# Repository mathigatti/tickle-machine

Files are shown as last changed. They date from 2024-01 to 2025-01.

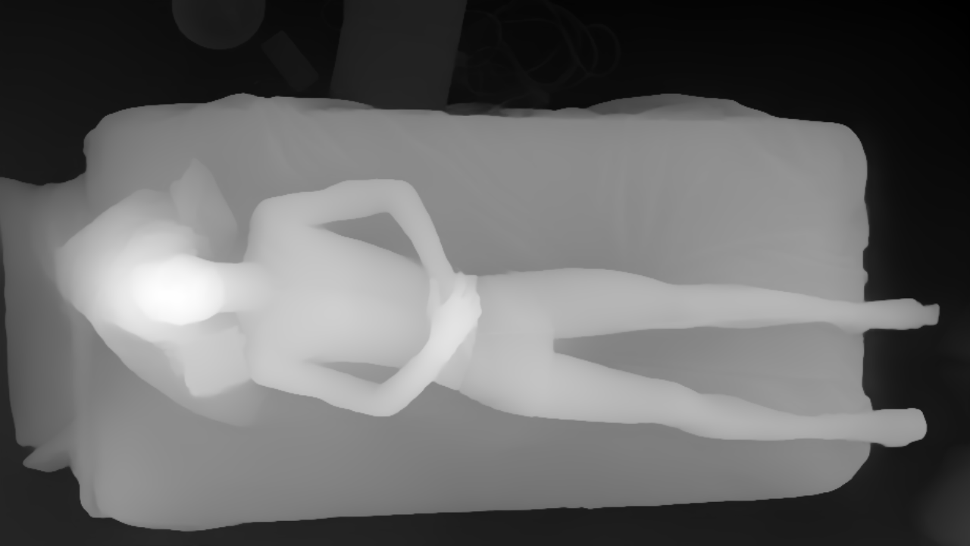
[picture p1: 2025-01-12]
src/move/depth.png

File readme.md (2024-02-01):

notas

- pi x diamtetro x vueltas = cantida de cable recorrido
- microsteps se habilitan mandando m0, m1 y m2 a 5V. (2,4,8, ... 32) del DRV. Una vuelta sin microsteps es 200 sin microsteps, con los microsteps gana mucho torque
- seteo potencimetro del dvr. Arrancar girando todo en sentido horario y probando girarlo de a poco hasta que ande, chequeando tambien que no caliente mucho

## cuestiones de montaje
para la sujecion de motores recomiendo utilizar [esta pieza 3d](https://www.thingiverse.com/thing:3539999) o similes
 * medidas de tornillos M3 x 6 mm

A su vez en el proyecto se encuentran poleas desarrolladas para el caso.
* pensadas para utilizar un tornillo y tuerca  de 5/32 x 3/4 (20mm)
  se realizo una prueba en [poleas para cadenas de cortinas](https://www.thingiverse.com/thing:3147) blackout pero fue descartado por el error acumulado; dejando el diseño del mismo para futuras investigaciones 

# para la proxima

- ver de usar el ramp
- incorporar segundo motor y empezar a investigar como manejarlos

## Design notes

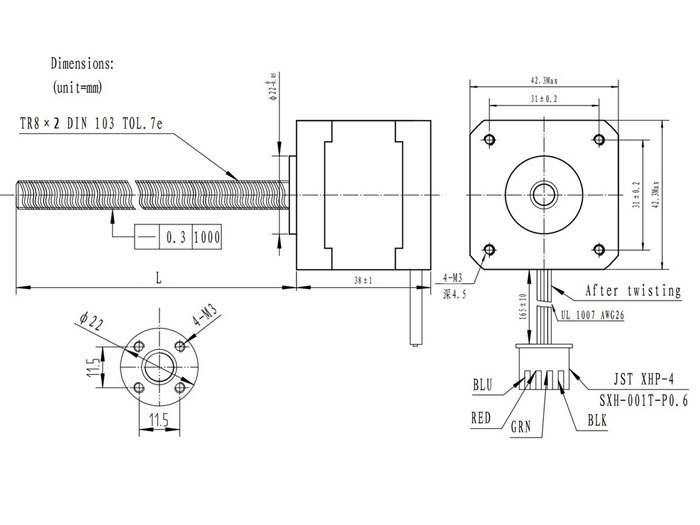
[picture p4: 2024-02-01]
ref tecnicas/mmpp038b.jpg

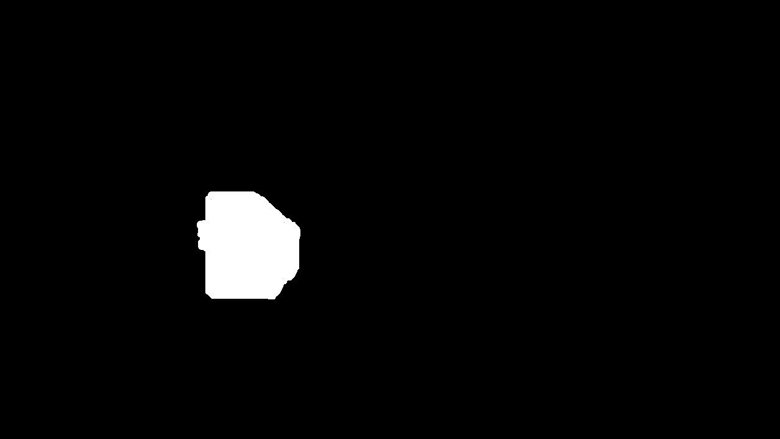
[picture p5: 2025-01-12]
src/move_simplified/mask.jpg

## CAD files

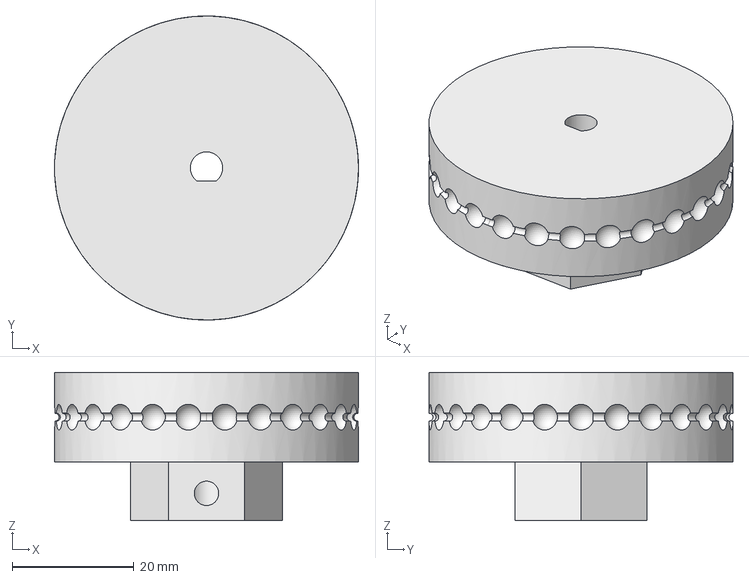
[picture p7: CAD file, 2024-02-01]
modelos 3d/desings/freecad/agarre parametrico y cortina.FCStd
49.9 x 49.9 x 24.4 mm

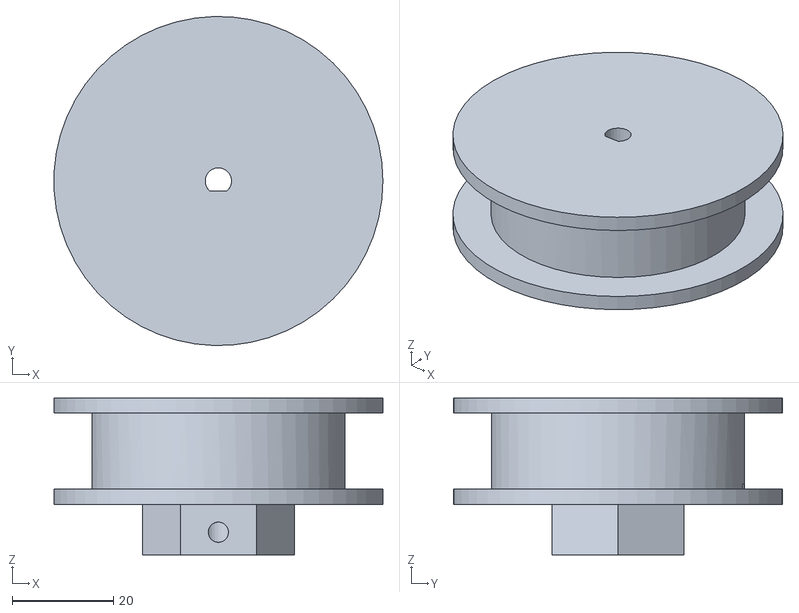
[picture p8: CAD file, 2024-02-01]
modelos 3d/stls/carretel_v4-base.stl
64.9 x 65.0 x 31.0

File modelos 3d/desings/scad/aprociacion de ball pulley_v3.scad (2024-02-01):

tolerancia=0.015;
offset_whell=0;
detalle=20;
ball_diameter = tolerancia+ 4.2;
ball_count = 96; // for regular pully;wd
link_largo =   tolerancia+  1.8;
// ball_spacing = 5.1; // The distance from the centre of one ball to the next
ball_spacing = ball_diameter+link_largo; // The distance from the centre of one ball to the next
//link_diameter = 0.9;
link_diameter =  tolerancia+  1.28;

PI = 3.1415927;
wheel_diameter =  tolerancia+  ball_count*ball_spacing / PI;
wheel_height =   ball_diameter*3.5;

pulley_height = wheel_height ;

module pulley () {
 difference(){
	difference()
	{
		cylinder (pulley_height, r = wheel_diameter/2+offset_whell, center=true, $fn = ball_count);

		for (i = [1:ball_count])
		{	
			rotate ([0, 0, (360/ball_count) * i])		
			translate ([wheel_diameter/2,0,0])
			sphere (r = ball_diameter/2,$fn=detalle);
     
		}

	}
  	
		rotate ([0, 0, -90]) // Rotate -90 to match face direction of cylinder
		rotate_extrude (convexity = 5, $fn = ball_count)
		translate ([wheel_diameter/2, 0, 0])
		circle (r = link_diameter/2, center = true);
 }
}

//translate ([0, 0, pulley_height/2])
pulley(); 

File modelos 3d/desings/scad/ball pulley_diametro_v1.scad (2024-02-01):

PI = 3.1415927;

tolerancia=0.015;
detalle=20;
diametro_ideal=50;

ball_diameter = tolerancia+ 4.2;
//cantidad = 96; // for regular pully;wd
link_largo =   tolerancia+  1.8;
espaciado = ball_diameter+link_largo; 

cantidad= round(diametro_ideal/espaciado*PI);
//echo(cantidad);

//link_diameter = 0.9;
link_diameter =  tolerancia+  1.28;

diametro =  cantidad*espaciado / PI;
altura =   ball_diameter*3.5;

altura_agarre = altura ;

module pulley () {
 difference(){
	difference()
	{
		cylinder (altura_agarre, r = diametro/2, center=true, $fn = cantidad);

		for (i = [1:cantidad])
		{	
			rotate ([0, 0, (360/cantidad) * i])		
			translate ([diametro/2,0,0])
			sphere (r = ball_diameter/2,$fn=detalle);
     
		}

	}
  	
		rotate ([0, 0, -90]) // Rotate -90 to match face direction of cylinder
		rotate_extrude (convexity = 5, $fn = cantidad)
		translate ([diametro/2, 0, 0])
		circle (r = link_diameter/2, center = true);
 }
}

//translate ([0, 0, altura_polea/2])
pulley(); 

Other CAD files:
modelos 3d/desings/freecad/carretel_v4.FCStd
modelos 3d/stls/agarre y polea cortina v1.stl

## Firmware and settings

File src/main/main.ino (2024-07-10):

#include <AccelStepper.h>

#define X_STEP_PIN A0
#define X_DIR_PIN A1
#define X_ENABLE_PIN 38

#define Y_STEP_PIN 46
#define Y_DIR_PIN 48
#define Y_ENABLE_PIN A8

#define Z_STEP_PIN A6
#define Z_DIR_PIN A7
#define Z_ENABLE_PIN A2

#define X_MIN 3
#define Y_MIN 18
#define Z_MIN 14

// Global variables
double x_total_cm = 20;
double z_total_cm = 19;

double diametro_cm = 5;
double perimetro = PI * diametro_cm;
int steps_por_vuelta = 6400;
double cm_a_steps = steps_por_vuelta / perimetro;
int steps_m1, steps_m2, steps_m3;

// Constantes

struct Vector {
  double x;
  double y;
  double z;
};

// Valores de inicio
double largo_motor_1 = 15;
double largo_motor_2 = x_total_cm-largo_motor_1;
double largo_motor_3 = 42;

Vector posiciones[] = {
  {100.0, 100.0, 100.0}
};

int lenVector = sizeof(posiciones) / sizeof(posiciones[0]);
int idx = 0;

void printear(String s, double val) {
  Serial.print(s + " : ");
  Serial.println(val);
}

void printear(String s, int val) {
  Serial.print(s + " : ");
  Serial.println(val);
}
void printear(String s, float val) {
  Serial.print(s + " : ");
  Serial.println(val);
}

void printear(String s, char val) {
  Serial.print(s + " : ");
  Serial.println(val);
}

void printear(String s, long val) {
  Serial.print(s + " : ");
  Serial.println(val);
}


void printear(String s) {
  Serial.println(s);
}

void calibrar_motores(AccelStepper motorX, AccelStepper motorY, AccelStepper motorZ, int *steps_motor_1, int *steps_motor_2, int *steps_motor_3) {
  /* ESTE CODIGO ASUME QUE EL MOTOR X TIENE HILO DE SOBRE SIEMPRE */
  int callibrate_steps = int(10 * cm_a_steps);
  // 1.
  // Mover motorX hasta que apriete el final de carrera
  bool X_SET = false;

  while (!X_SET) {
    motorX.move(-1*callibrate_steps);

    while (!X_SET && abs(motorX.distanceToGo()) > 0) {
      motorX.run();

      if (digitalRead(X_MIN) == LOW){
        X_SET = true;
      }

    }

  }

  Serial.println(digitalRead(X_MIN));

  bool Y_SET = false;
  bool Z_SET = false;
  *steps_motor_1 = 0;
  *steps_motor_2 = 0;
  // 2.
  // Mover motores hasta que se apriete el final de carrera del motorY
  while (!Y_SET) {
    motorY.move(-1*callibrate_steps);
    motorX.move(callibrate_steps);
    while (!Y_SET && abs(motorY.distanceToGo()) > 0) {
      motorY.run();
      motorX.run();
      *steps_motor_1+=1;
      if (digitalRead(Y_MIN) == LOW){
        Y_SET = true;
      }

    }
  }
  Serial.println(digitalRead(Y_MIN));

  *steps_motor_3 = 0;

  // FALTA HACER CALCULO DE QUE X SE VA A MOVER LA DISTANCIA DE X A Z MENOS LO QUE TIENE AHORA DE SOGA
  //motorX.move(COMPLETAR);

  while (!Z_SET) {
    motorY.move(callibrate_steps);
    motorZ.move(-1*callibrate_steps);
    while (!Z_SET && abs(motorZ.distanceToGo()) > 0) {
      //motorX.run();
      motorY.run();
      motorZ.run();
      *steps_motor_1+=1;
      *steps_motor_2+=1;
      if (digitalRead(Z_MIN) == LOW){
        Z_SET = true;
      }

    }
  }
  Serial.println(digitalRead(Y_MIN));

}



void update_steps(double x, double y, double z, int *steps_motor_1, int *steps_motor_2, int *steps_motor_3) {
  double largo_motor_1_viejo = largo_motor_1;
  double largo_motor_2_viejo = largo_motor_2;
  double largo_motor_3_viejo = largo_motor_3;

  largo_motor_1 = sqrt(pow(x, 2) + pow(y, 2) + pow(z, 2));
  largo_motor_2 = sqrt(pow(x_total_cm - x, 2) + pow(y, 2) + pow(z, 2));
  largo_motor_3 = sqrt(pow(x_total_cm/2 - x, 2) + pow(y, 2) + pow(z_total_cm - z, 2));

  double diferencia_motor_1 = largo_motor_1 - largo_motor_1_viejo;
  double diferencia_motor_2 = largo_motor_2 - largo_motor_2_viejo;
  double diferencia_motor_3 = largo_motor_3 - largo_motor_3_viejo;

  *steps_motor_1 = int(cm_a_steps * diferencia_motor_1);
  *steps_motor_2 = int(cm_a_steps * diferencia_motor_2);
  *steps_motor_3 = int(cm_a_steps * diferencia_motor_3);
}


int x_i;
int y_i;
int z_i;


int numberOfSteps = 400;
byte ledPin = 13;
int pulseWidthMicros = 20;    // microseconds
int millisbetweenSteps = 20;  // milliseconds - or try 1000 for slower steps

int vueltas = 4;
int steps = 200;
int microsteps = 32;

AccelStepper motorY(1, Y_STEP_PIN, Y_DIR_PIN);
AccelStepper motorX(1, X_STEP_PIN, X_DIR_PIN);
AccelStepper motorZ(1, Z_STEP_PIN, Z_DIR_PIN);

void setup() {

  Serial.begin(9600);
  Serial.println("Starting StepperTest");
  digitalWrite(ledPin, LOW);

  pinMode(X_MIN, INPUT);
  pinMode(Y_MIN, INPUT);
  pinMode(Z_MIN, INPUT);

  pinMode(Y_STEP_PIN, OUTPUT);
  pinMode(Y_DIR_PIN, OUTPUT);
  pinMode(Y_ENABLE_PIN, OUTPUT);

  pinMode(X_STEP_PIN, OUTPUT);
  pinMode(X_DIR_PIN, OUTPUT);
  pinMode(X_ENABLE_PIN, OUTPUT);

  pinMode(Z_STEP_PIN, OUTPUT);
  pinMode(Z_DIR_PIN, OUTPUT);
  pinMode(Z_ENABLE_PIN, OUTPUT);

  pinMode(ledPin, OUTPUT);

  int speed = int(steps * microsteps);
  motorY.setMaxSpeed(speed * 2);
  motorY.setSpeed(speed);
  motorY.setAcceleration(speed * 4);

  motorX.setMaxSpeed(speed * 2);
  motorX.setSpeed(speed);
  motorX.setAcceleration(speed * 4);

  motorZ.setMaxSpeed(speed * 2);
  motorZ.setSpeed(speed);
  motorZ.setAcceleration(speed * 4);

  calibrar_motores(motorX, motorY,motorZ, &steps_m1, &steps_m2, &steps_m3);
}

void loop() {
  /*
  int max_position = steps * microsteps * vueltas;
  motorY.run();
  motorX.run();
  motorZ.run();

  if (motorY.distanceToGo() == 0 && motorX.distanceToGo() == 0 && motorZ.distanceToGo() == 0) {
    printear("-----------------------");
    printear("currentPosition", motorX.currentPosition());

    printear("cambio objetivo");

    idx++;
    if (idx == lenVector) {
      idx = 0;
    }
    x_i = posiciones[idx].x;
    y_i = posiciones[idx].y;
    z_i = posiciones[idx].z;
    printear("posX destino", x_i);
    update_steps(x_i, y_i, z_i, &steps_m1, &steps_m2, &steps_m3);

    motorY.move(-steps_m1);
    motorX.move(steps_m2);
    motorZ.move(steps_m3);
    printear("steps_m1", steps_m1);
    printear("steps_m2", steps_m2);
    printear("steps_m2", steps_m3);

    printear("-----------------------");

    delay(2000);

  }
  */
}

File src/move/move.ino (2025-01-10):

#include <AccelStepper.h>

#define X_STEP_PIN A0
#define X_DIR_PIN A1
#define X_ENABLE_PIN 38

#define Y_STEP_PIN 46
#define Y_DIR_PIN 48
#define Y_ENABLE_PIN A8

#define Z_STEP_PIN A6
#define Z_DIR_PIN A7
#define Z_ENABLE_PIN A2

#define X_MIN 3
#define Y_MIN 18
#define Z_MIN 14

double diametro_cm = 5;
double perimetro = PI * diametro_cm;
int steps_por_vuelta = 6400;
double cm_a_steps = steps_por_vuelta / perimetro;

AccelStepper motorX(1, X_STEP_PIN, X_DIR_PIN);
AccelStepper motorY(1, Y_STEP_PIN, Y_DIR_PIN);
AccelStepper motorZ(1, Z_STEP_PIN, Z_DIR_PIN);

int numberOfSteps = 400;
byte ledPin = 13;
int pulseWidthMicros = 20;    // microseconds
int millisbetweenSteps = 20;  // milliseconds - or try 1000 for slower steps

int vueltas = 4;
int steps = 200;
int microsteps = 32;

// Struct for 3D coordinates
struct Coordinate3D {
  double x;
  double y;
  double z;
};

double movement_length = 10.;

void handle_serial_command(char command) {
  switch (command) {
    case 'N': // Moverse mas
      movement_length += 1;
      if (movement_length > 100)
        movement_length = 100;
      break;
    case 'M': // Moverse menos
      movement_length -= 1;
      if (movement_length < 1)
        movement_length = 1;
      break;
    case 'Y': // Motor X Up
      motorX.move(cm_a_steps * -movement_length);
      break;
    case 'H': // Motor X Down
      motorX.move(cm_a_steps * movement_length);
      break;
    case 'U': // Motor Y Up
      motorY.move(cm_a_steps * -movement_length);
      break;
    case 'J': // Motor Y Down
      motorY.move(cm_a_steps * movement_length);
      break;
    case 'I': // Motor Z Up
      motorZ.move(cm_a_steps * -movement_length);
      break;
    case 'K': // Motor Z Down
      motorZ.move(cm_a_steps * movement_length);
      break;
    default:
      break;
  }
}

void setup() {
  Serial.begin(9600);
  Serial.println("Starting StepperTest");
  digitalWrite(ledPin, LOW);

  pinMode(X_MIN, INPUT);
  pinMode(Y_MIN, INPUT);
  pinMode(Z_MIN, INPUT);

  pinMode(Y_STEP_PIN, OUTPUT);
  pinMode(Y_DIR_PIN, OUTPUT);
  pinMode(Y_ENABLE_PIN, OUTPUT);

  pinMode(X_STEP_PIN, OUTPUT);
  pinMode(X_DIR_PIN, OUTPUT);
  pinMode(X_ENABLE_PIN, OUTPUT);

  pinMode(Z_STEP_PIN, OUTPUT);
  pinMode(Z_DIR_PIN, OUTPUT);
  pinMode(Z_ENABLE_PIN, OUTPUT);

  pinMode(ledPin, OUTPUT);

  int speed = int(steps * microsteps * 20);
  //speed = 30000;
  
  motorY.setMaxSpeed(speed * 2);
  motorY.setSpeed(speed);
  motorY.setAcceleration(speed * 4);

  motorX.setMaxSpeed(speed * 2);
  motorX.setSpeed(speed);
  motorX.setAcceleration(speed * 4);

  motorZ.setMaxSpeed(speed * 2);
  motorZ.setSpeed(speed);
  motorZ.setAcceleration(speed * 4);


}

Coordinate3D parse_coordinates(String message) {
  // Assuming message is in the format "x,y,z"
  Coordinate3D coord;
  int firstCommaIndex = message.indexOf(',');
  int secondCommaIndex = message.indexOf(',', firstCommaIndex + 1);

  if (firstCommaIndex == -1 || secondCommaIndex == -1) {
    Serial.println("Invalid coordinate format");
    return coord;
  }

  String xString = message.substring(0, firstCommaIndex);
  String yString = message.substring(firstCommaIndex + 1, secondCommaIndex);
  String zString = message.substring(secondCommaIndex + 1);

  coord.x = xString.toFloat();
  coord.y = yString.toFloat();
  coord.z = zString.toFloat();

  // Now print the coordinates
  Serial.print("Parsed coordinates: (");
  Serial.print(coord.x);
  Serial.print(", ");
  Serial.print(coord.y);
  Serial.print(", ");
  Serial.print(coord.z);
  Serial.println(")");
  return coord;
}

void loop() {
  motorX.run();
  motorY.run();
  motorZ.run();

  while (Serial.available()) {
    char command = Serial.read();
    if (command == '(') {
      // Start reading the message
      String message = "";
      unsigned long startTime = millis(); // Get the current time
      const unsigned long timeout = 1000; // Timeout duration in milliseconds (1 second)

      while (true) {
        // Check for timeout
        if (millis() - startTime > timeout) {
          Serial.println("Timeout while reading message");
          break; // Exit the loop if timeout occurs
        }
        // Wait until data is available
        if (Serial.available()) {
          char c = Serial.read();
          if (c == ')') {
            // End of message
            break;
          }
          message += c;
        }
      }
      // Now print the full message
      Serial.println("Received message: " + message);

      // Parse the coordinates
      Coordinate3D coord = parse_coordinates(message);
      motorX.move(cm_a_steps * coord.x);
      motorY.move(cm_a_steps * coord.y);
      motorZ.move(cm_a_steps * coord.z);


    } else {
      handle_serial_command(command);
    }
  }
}

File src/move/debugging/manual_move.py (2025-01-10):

import serial
import random
import threading
from time import sleep
from pynput import keyboard

# Configure the serial connection
arduino_port = "/dev/ttyUSB0"  # Replace with your Arduino's serial port
baud_rate = 9600       # Must match the baud rate in the Arduino sketch

X_TOTAL_CM=180
Y_TOTAL_CM=280
Z_TOTAL_CM=230

# Create a serial connection
try:
    ser = serial.Serial(arduino_port, baud_rate, timeout=1)
    print(f"Connected to Arduino on {arduino_port}")
except Exception as e:
    print(f"Failed to connect to Arduino: {e}")
    exit()

# Function to read from Arduino
def read_from_arduino():
    while True:
        try:
            if ser.in_waiting > 0:
                message = ser.readline().decode().strip()
                if message:
                    print(f"Received: {message}")
        except Exception as e:
            print(f"Error reading from Arduino: {e}")
            break

def random_point(x_min, x_max, y, z_min, z_max):
    granularity = 100
    x = random.randint(0,granularity)/granularity
    z = random.randint(0,granularity)/granularity
    
    x = x*(x_max-x_min)+x_min
    z = z*(z_max-z_min)+z_min
    return str((float(round(x)), float(y), float(round(z))))

def valid_coords(coord):
    x,y,z = coord
    # Function to calculate the area of a triangle given its vertices
    def triangle_area(x1, z1, x2, z2, x3, z3):
        return abs((x1 * (z2 - z3) + x2 * (z3 - z1) + x3 * (z1 - z2)) / 2.0)

    # Vertices of the triangle
    x1, z1 = 0, 0
    x2, z2 = X_TOTAL_CM, 0
    x3, z3 = X_TOTAL_CM / 2, Z_TOTAL_CM

    # Total area of the triangle
    total_area = triangle_area(x1, z1, x2, z2, x3, z3)

    # Areas of triangles formed with the point (x, z)
    area1 = triangle_area(x, z, x2, z2, x3, z3)
    area2 = triangle_area(x1, z1, x, z, x3, z3)
    area3 = triangle_area(x1, z1, x2, z2, x, z)

    # Check if the sum of the areas matches the total area
    return total_area == (area1 + area2 + area3) and 0 <= y <= Y_TOTAL_CM

# Start the read thread
read_thread = threading.Thread(target=read_from_arduino)
read_thread.daemon = True
read_thread.start()

# Define a function to send messages to the Arduino
def send_to_arduino(message):
    try:
        ser.write(message.encode())  # Send the message
        print(f"Sent: {message}")
    except Exception as e:
        print(f"Error sending to Arduino: {e}")

# Define a callback for key presses
def on_press(key):
    try:
        if key.char == "1":
            with open("coords.txt", 'r') as f:
                coords = f.read().split(" ")
            for coord in coords:
                send_to_arduino(str(coord).replace(" ", ""))
                sleep(7)
        if key.char == "2":
            for _ in range(12):
                center = (90,0,80)
                coord = random_point(center[0]-30,center[0]+30,center[1]+30,center[2]-70,center[2]+40)
                
                send_to_arduino(str(coord))
                sleep(7)

                send_to_arduino(str(center))
                sleep(7)

        if key.char == "3":
            for _ in range(8):
                center = (90,0,80)
                coord = random_point(center[0]-30,center[0]+30,center[1]+30,center[2]-70,center[2]+40)
                
                send_to_arduino(str(coord))
                sleep(4)


        if key.char == "4":
            for _ in range(4):
                x, y, z = (90,0,80) 
                d = 100               
                for coord in [(x - d, y, z), (x, y, z-d), (x + d, y, z), (x, y, z+d)]:
                    send_to_arduino(str(coord))
                    sleep(4)


        if key.char in {'f','r','z','q', 'a', 'w', 's', 'e', 'd', 'y', 'h', 'u', 'j', 'i', 'k', 'm', 'n', 'b', 'c','v'}:
            if key.char.upper() == "Z":
                raise Exception("Bye! :)")
            send_to_arduino(key.char.upper())  # Send the command in uppercase
    except AttributeError:
        # Handle special keys (non-character keys)
        pass

# Define a callback for key releases
def on_release(key):
    if key == keyboard.Key.esc:
        # Stop listener
        print("Exiting...")
        return False

# Start listening to the keyboard
with keyboard.Listener(on_press=on_press, on_release=on_release) as listener:
    listener.join()

# Close the serial connection when done
if ser.is_open:
    ser.close()

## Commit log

2024-01-10 test motores
2024-01-10 lo que llegamos a hacer hoy
2024-01-23 piezas 3d documentadas
    [agarre parametrico y cortina.FCStd, agarre y polea cortina v1.stl, aprociacion de ball pulley_v3.scad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]
2024-02-27 codigo que funciona
2024-07-10 3d endstop wip
2024-07-17 sumando stl agarre
2024-12-02 prototype 1
